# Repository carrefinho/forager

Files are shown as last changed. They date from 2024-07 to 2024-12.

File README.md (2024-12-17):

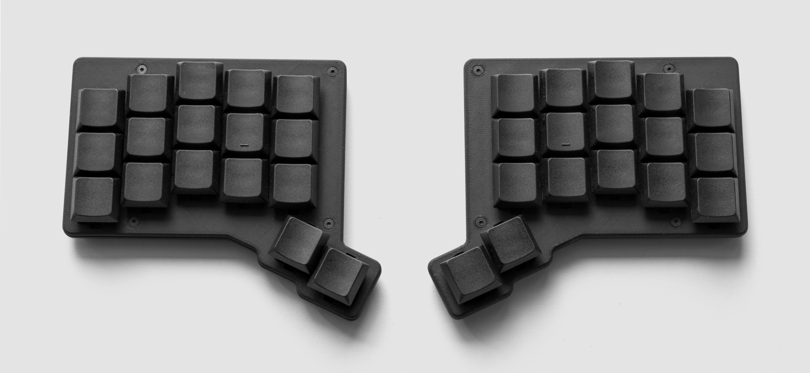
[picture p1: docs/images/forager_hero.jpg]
Forager keyboard in white


# Forager

Forager is a Voyager-inspired 34-key low-profile wireless split keyboard powered by ZMK.

> why does the large Voyager not simply eat the small Forager?

## Design

- Condensed [ZSA Voyager](https://www.zsa.io/voyager) layout without outer pinkie column and number row
- Hot-swap Kailh Choc V1 switches in Choc (18x17mm) spacing with Voyager-esque switch puller grooves

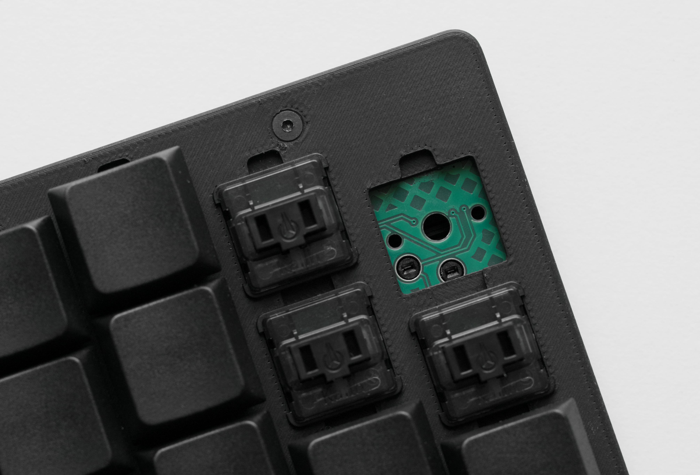
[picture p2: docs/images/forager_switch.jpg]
Switch-plate cutouts


- Wireless only with Seeed XIAO nRF52840 running ZMK firmware
- Magnetic tenting legs inspired by Voyager and [Unicorne](https://www.boardsource.xyz/products/unicorne)

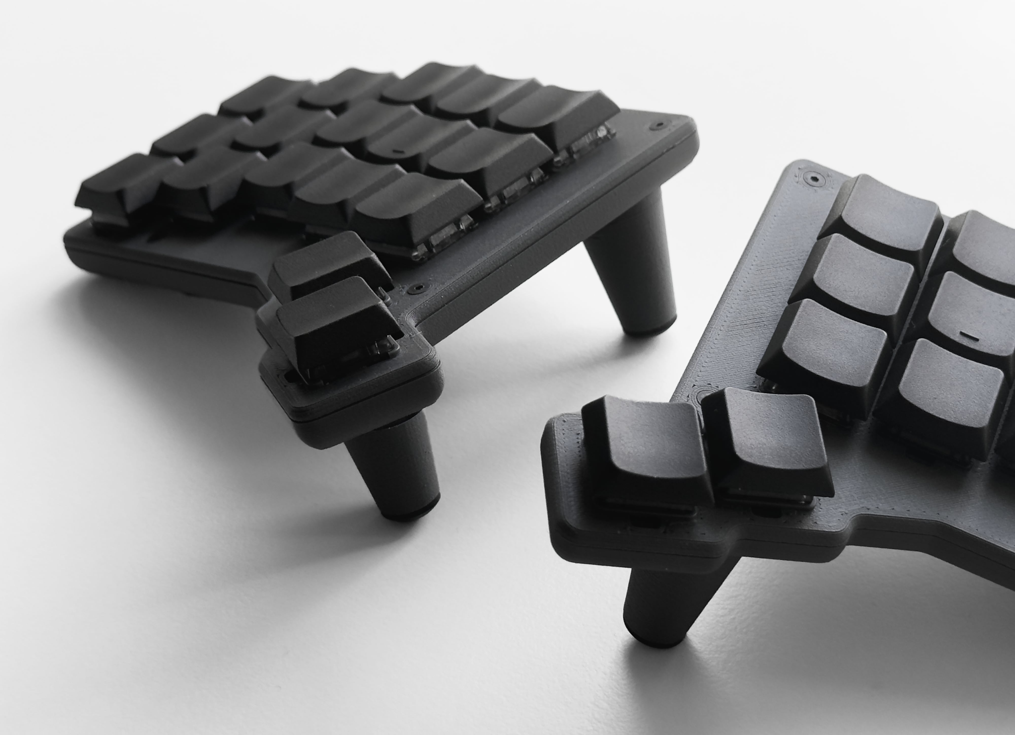
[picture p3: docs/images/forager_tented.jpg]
Forager keyboard with magnetic tenting legs attached


- Compact silhouette without the usual blank space occupied by controller
- Fully enclosed with 3D-printed two-piece case
- Minimal BOM by utilizing XIAO nRF52840's onboard RGB LED and reset button

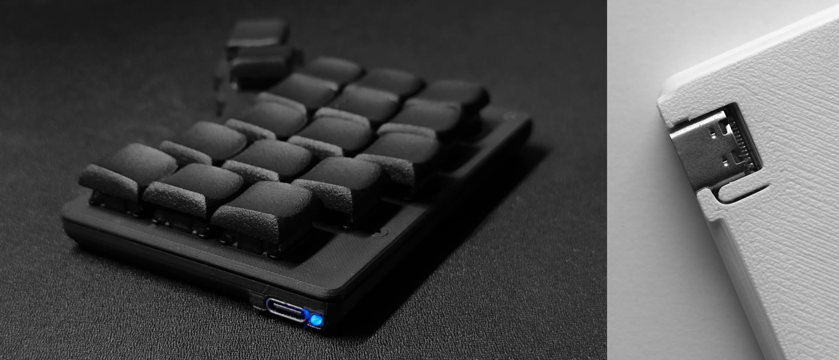
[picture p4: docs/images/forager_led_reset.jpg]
Forager keyboard with LED indicator lit up in blue alongside reset button on the bottom


## Build Guide and Parts List

[Find the build guide here.](/docs/build-guide.md)

## Firmware

[Find the ZMK module here.](https://github.com/carrefinho/forager-zmk-module)

## Credits

- [ZSA Voyager](https://www.zsa.io/voyager): overall layout & aesthetics
- [GEIGEIGEIST/TOTEM](https://github.com/GEIGEIGEIST/TOTEM): XIAO PCB footprint and general placement
- [ebastler/marbastlib](https://github.com/ebastler/marbastlib): symbols and PCB footprints
- [caksoylar/zmk-rgbled-widget](https://github.com/caksoylar/zmk-rgbled-widget): RGB LED functionality

## Gallery

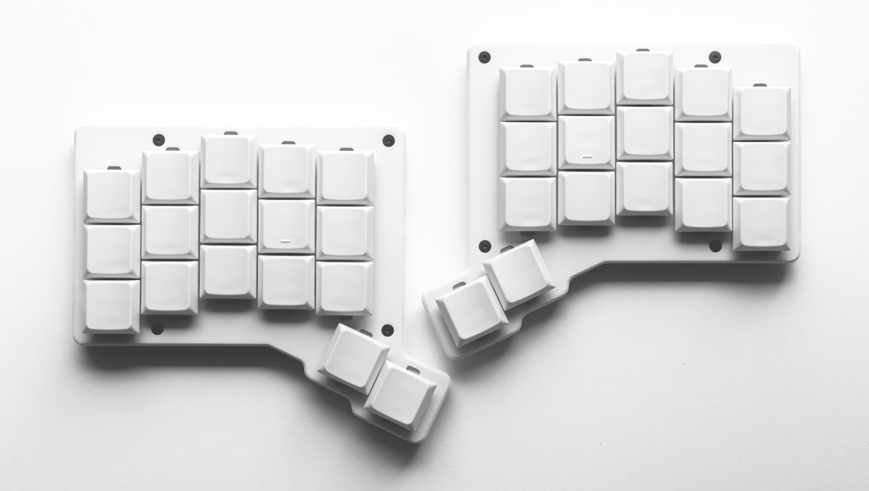
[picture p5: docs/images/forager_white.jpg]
Forager keyboard in white

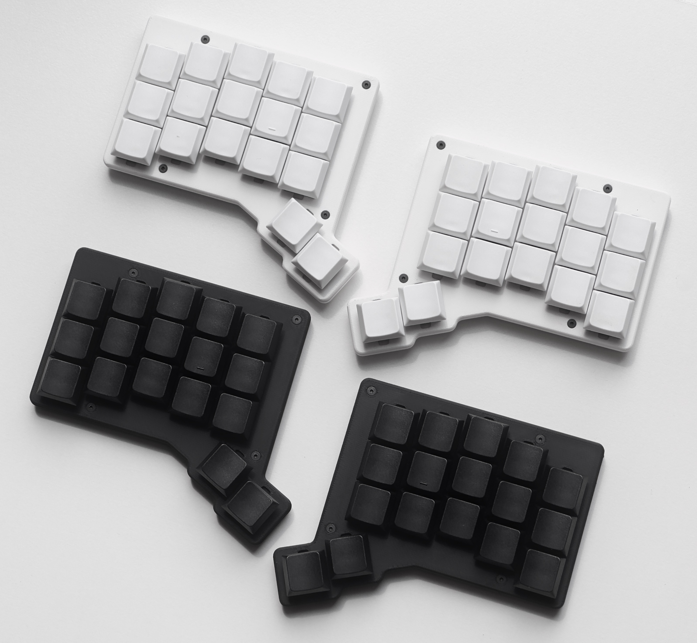
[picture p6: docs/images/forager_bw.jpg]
Forager keyboard in black and white

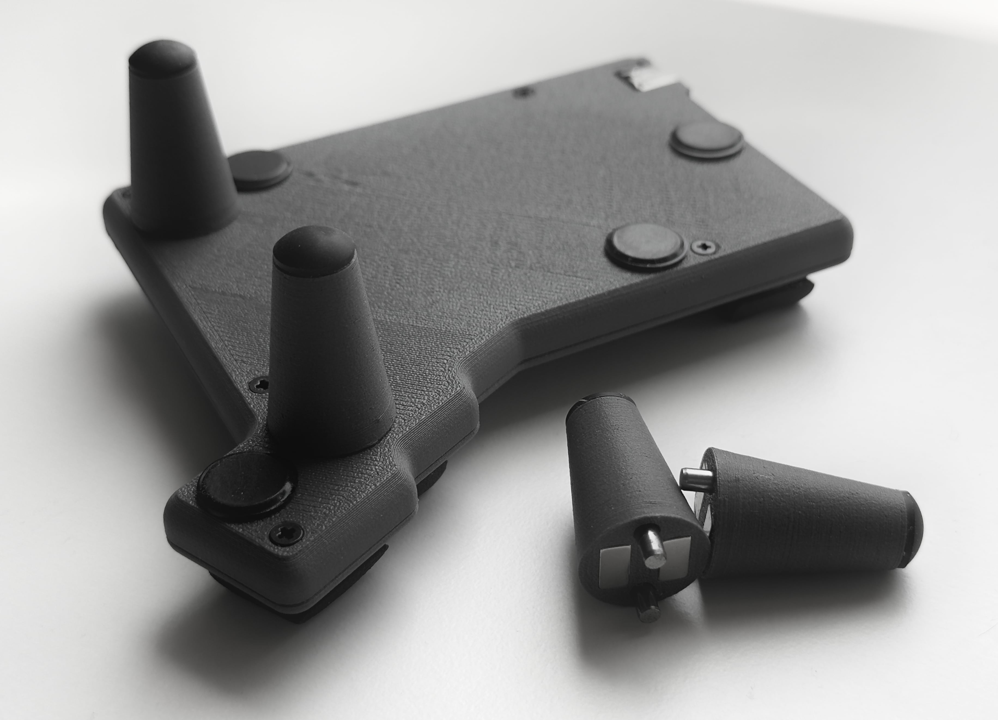
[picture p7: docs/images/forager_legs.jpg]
Forager keyboard with detached tenting leg

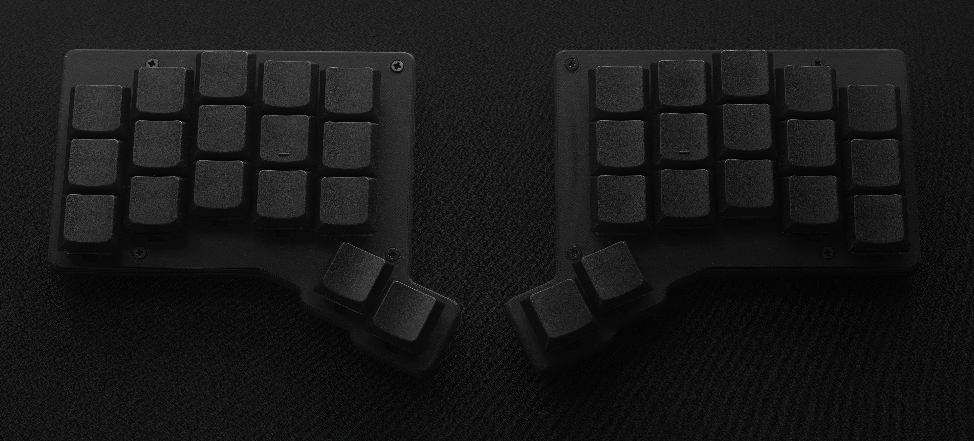
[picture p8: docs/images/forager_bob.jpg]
Forager keyboard in black


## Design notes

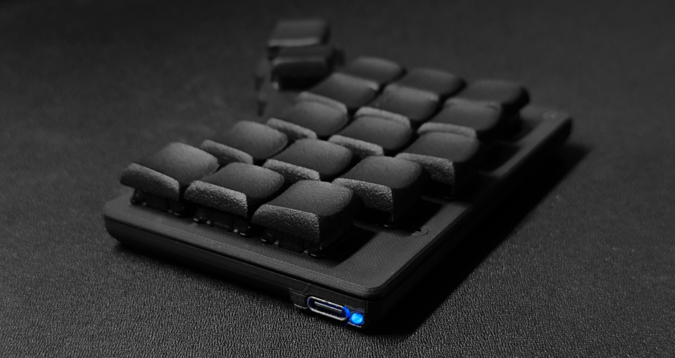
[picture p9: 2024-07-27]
docs/images/forager_led.jpg

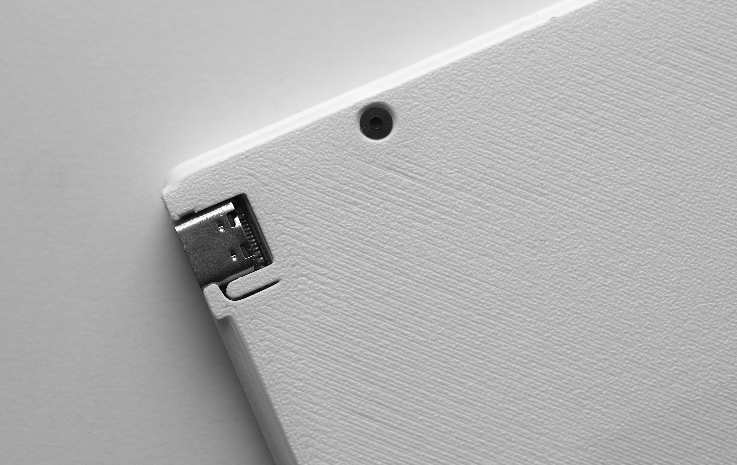
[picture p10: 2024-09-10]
docs/images/forager_reset.jpg

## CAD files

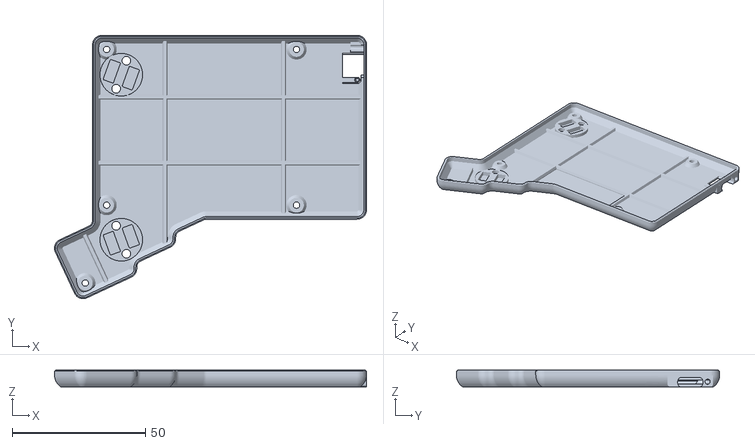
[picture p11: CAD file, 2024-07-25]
case/RBase.stl
117.2 x 98.9 x 6.20

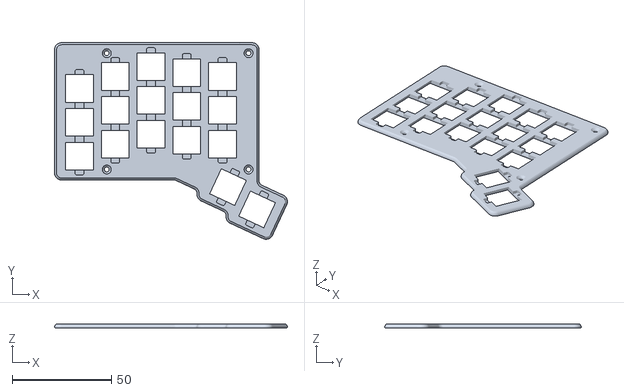
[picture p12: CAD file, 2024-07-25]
case/LTop.stl
117.2 x 98.9 x 2.20

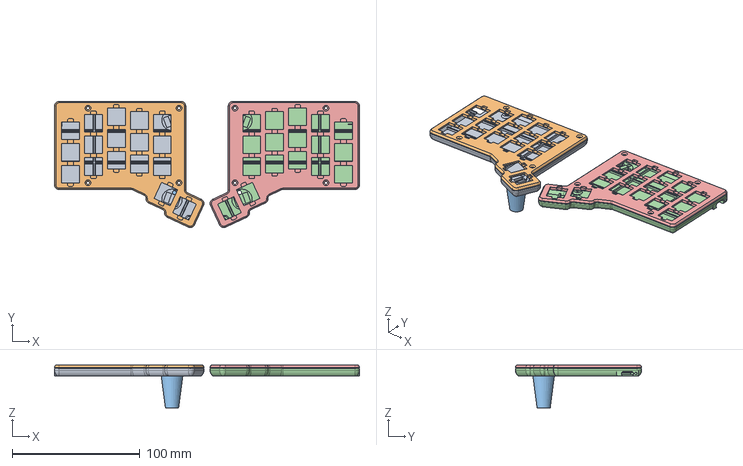
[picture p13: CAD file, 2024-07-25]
case/Forager Case.step
239.1 x 98.9 x 33.4 mm

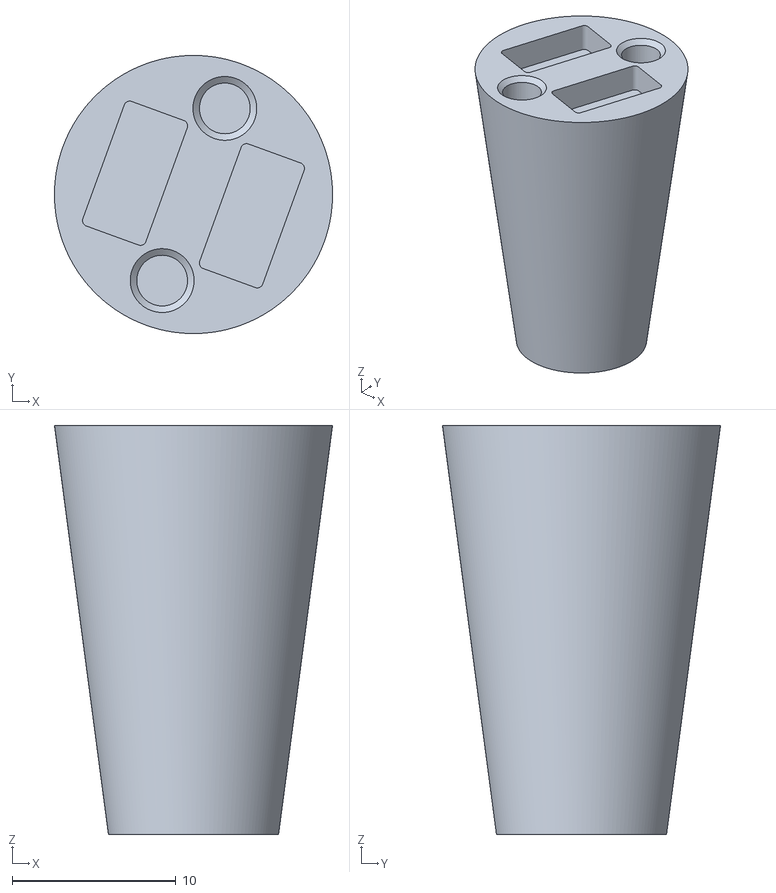
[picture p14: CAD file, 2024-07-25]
case/legs.stl
17.0 x 17.0 x 25.0

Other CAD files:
case/LBase.stl
case/RTop.stl

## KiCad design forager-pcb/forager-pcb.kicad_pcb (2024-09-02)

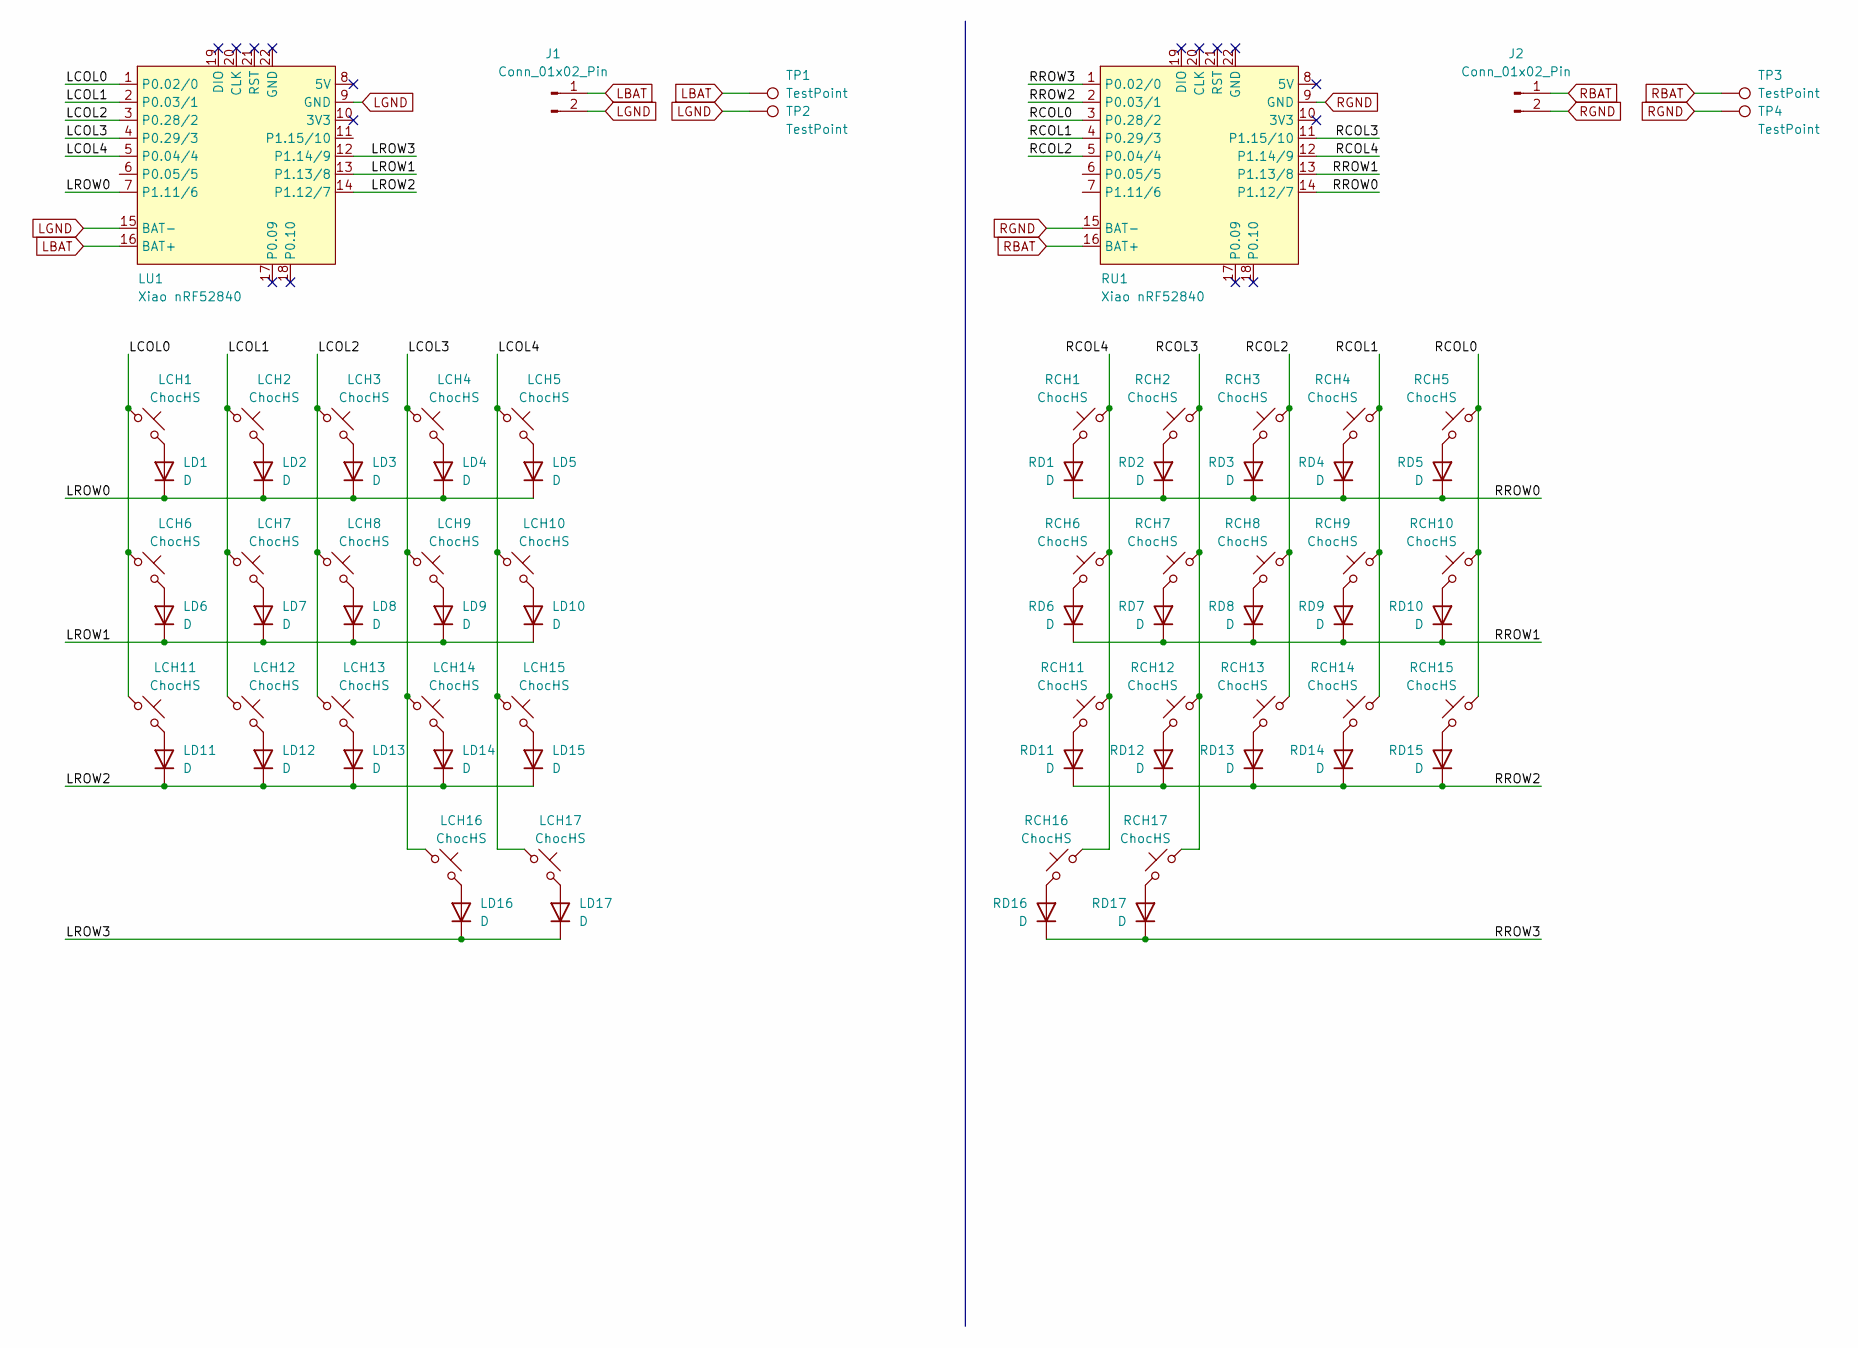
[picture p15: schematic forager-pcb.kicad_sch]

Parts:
J1, J2: Conn_01x02_Pin; JST_ACH_BM02B-ACHSS-GAN-ETF_1x02-1MP_P1.20mm_Vertical
LCH1, LCH2, LCH3, LCH4, LCH5, LCH6, LCH7, LCH8, LCH9, LCH10, LCH11, LCH12, LCH13, LCH14, LCH15, LCH16, LCH17: ChocHS; SW_choc_v1_HS_MBK
LD1, LD2, LD3, LD4, LD5, LD6, LD7, LD8, LD9, LD10, LD11, LD12, LD13, LD14, LD15, LD16, LD17: D; D_SOD-123
LU1: Xiao nRF52840; xiao-ble-smd-cutout
RCH1, RCH2, RCH3, RCH4, RCH5, RCH6, RCH7, RCH8, RCH9, RCH10, RCH11, RCH12, RCH13, RCH14, RCH15, RCH16, RCH17: ChocHS; SW_choc_v1_HS_MBK
RD1, RD2, RD3, RD4, RD5, RD6, RD7, RD8, RD9, RD10, RD11, RD12, RD13, RD14, RD15, RD16, RD17: D; D_SOD-123
RU1: Xiao nRF52840; xiao-ble-smd-cutout
TP1, TP2, TP3, TP4: TestPoint; TestPoint_Pad_D2.0mm

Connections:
/LCOL0: LCH1.1, LCH6.1, LCH11.1, LU1.1 (P0.02/0)
/LCOL1: LCH2.1, LCH7.1, LCH12.1, LU1.2 (P0.03/1)
/LCOL2: LCH3.1, LCH8.1, LCH13.1, LU1.3 (P0.28/2)
/LCOL3: LCH4.1, LCH9.1, LCH14.1, LCH16.1, LU1.4 (P0.29/3)
/LCOL4: LCH5.1, LCH10.1, LCH15.1, LCH17.1, LU1.5 (P0.04/4)
/LROW0: LD1.1 (K), LD2.1 (K), LD3.1 (K), LD4.1 (K), LD5.1 (K), LU1.7 (P1.11/6)
/LROW1: LD6.1 (K), LD7.1 (K), LD8.1 (K), LD9.1 (K), LD10.1 (K), LU1.13 (P1.13/8)
/LROW2: LD11.1 (K), LD12.1 (K), LD13.1 (K), LD14.1 (K), LD15.1 (K), LU1.14 (P1.12/7)
/LROW3: LD16.1 (K), LD17.1 (K), LU1.12 (P1.14/9)
/RCOL0: RCH5.1, RCH10.1, RCH15.1, RU1.3 (P0.28/2)
/RCOL1: RCH4.1, RCH9.1, RCH14.1, RU1.4 (P0.29/3)
/RCOL2: RCH3.1, RCH8.1, RCH13.1, RU1.5 (P0.04/4)
/RCOL3: RCH2.1, RCH7.1, RCH12.1, RCH17.1, RU1.11 (P1.15/10)
/RCOL4: RCH1.1, RCH6.1, RCH11.1, RCH16.1, RU1.12 (P1.14/9)
/RROW0: RD1.1 (K), RD2.1 (K), RD3.1 (K), RD4.1 (K), RD5.1 (K), RU1.14 (P1.12/7)
/RROW1: RD6.1 (K), RD7.1 (K), RD8.1 (K), RD9.1 (K), RD10.1 (K), RU1.13 (P1.13/8)
/RROW2: RD11.1 (K), RD12.1 (K), RD13.1 (K), RD14.1 (K), RD15.1 (K), RU1.2 (P0.03/1)
/RROW3: RD16.1 (K), RD17.1 (K), RU1.1 (P0.02/0)
LBAT: J1.1, LU1.16 (BAT+), TP1.1
LGND: J1.2, LU1.9 (GND), LU1.15 (BAT-), TP2.1
unnamed: LCH1.2, LD1.2 (A)
unnamed: LCH2.2, LD2.2 (A)
unnamed: LCH3.2, LD3.2 (A)
unnamed: LCH4.2, LD4.2 (A)
unnamed: LCH5.2, LD5.2 (A)
unnamed: LCH6.2, LD6.2 (A)
unnamed: LCH7.2, LD7.2 (A)
unnamed: LCH8.2, LD8.2 (A)
unnamed: LCH9.2, LD9.2 (A)
unnamed: LCH10.2, LD10.2 (A)
unnamed: LCH11.2, LD11.2 (A)
unnamed: LCH12.2, LD12.2 (A)
unnamed: LCH13.2, LD13.2 (A)
unnamed: LCH14.2, LD14.2 (A)
unnamed: LCH15.2, LD15.2 (A)
unnamed: LCH16.2, LD16.2 (A)
unnamed: LCH17.2, LD17.2 (A)
unnamed: RCH1.2, RD1.2 (A)
unnamed: RCH2.2, RD2.2 (A)
unnamed: RCH3.2, RD3.2 (A)
unnamed: RCH4.2, RD4.2 (A)
unnamed: RCH5.2, RD5.2 (A)
unnamed: RCH6.2, RD6.2 (A)
unnamed: RCH7.2, RD7.2 (A)
unnamed: RCH8.2, RD8.2 (A)
unnamed: RCH9.2, RD9.2 (A)
unnamed: RCH10.2, RD10.2 (A)
unnamed: RCH11.2, RD11.2 (A)
unnamed: RCH12.2, RD12.2 (A)
unnamed: RCH13.2, RD13.2 (A)
unnamed: RCH14.2, RD14.2 (A)
unnamed: RCH15.2, RD15.2 (A)
unnamed: RCH16.2, RD16.2 (A)
unnamed: RCH17.2, RD17.2 (A)
RBAT: J2.1, RU1.16 (BAT+), TP3.1
RGND: J2.2, RU1.9 (GND), RU1.15 (BAT-), TP4.1

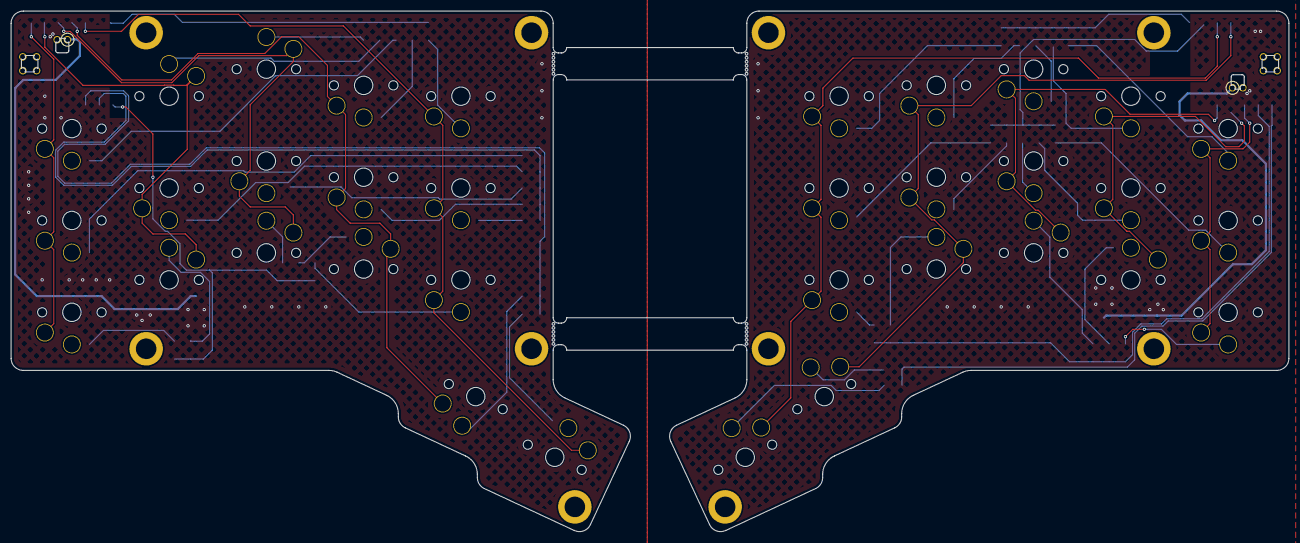
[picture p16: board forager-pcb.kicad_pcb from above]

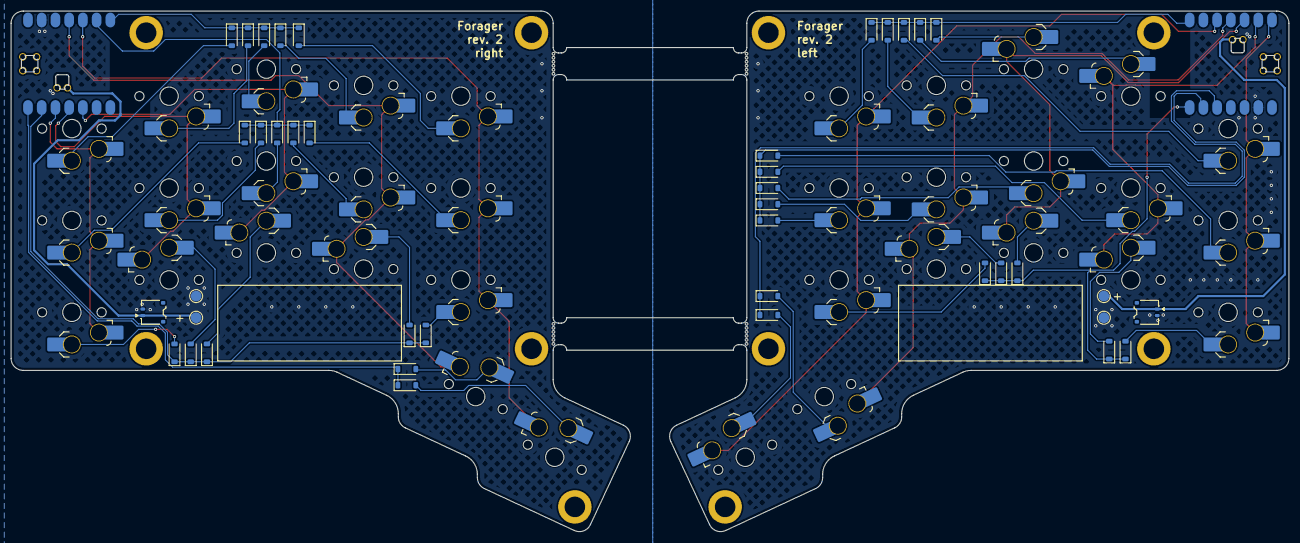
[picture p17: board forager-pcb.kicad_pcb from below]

Board: 2 copper layers, 236.5 x 96.3 mm, 76 parts (76 on the bottom side), 56 nets.

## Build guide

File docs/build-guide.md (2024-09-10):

# Forager Build Guide

## List of Components

| Part Name | Part Number | Count | Notes |
| --- | --- | ----- | ----- |
| Forager PCB | - | 1 | [Files here.](../forager-pcb/) |
| Seeed XIAO nRF52840 | - | 2 | Including Sense version; not compatible with other variants of the XIAO including RP2040 and ESP32-C3 |
| Choc V1 hot swap sockets | CPG135001S30 | 34 | |
| Diodes | 1N4148W | 34 | SOD-123 | - |
| Battery Connector | JST BM02B-ACHSS-GAN / MOLEX 781710002 | 2 (OPTIONAL) | Only required for batteries with JST ACH/Molex Pico-EZmate connectors. The two types should be compatible in both PCB footprint and physical connector.
| Battery | 301230 / 401230 | 2 | Widely available from many keyboard vendors. [Little Keyboards sell ones with JST ACH connectors](https://www.littlekeyboards.com/collections/new-products/products/battery-w-jst-connector) for use with the connector above.
| SMD M2 Nuts | SMTSO2020MTJ | 10 | https://www.lcsc.com/product-detail/SMD-round-nut_Sinhoo-SMTSO2020MTJ_C2916384.html |

### Case

| Part Name | Part Number | Count | Notes |
| --- | --- | ----- | ----- |
| 3D-printed Case | - | 4 | [Files here.](../case/) Designed for FDM. Some walls may be too thin for certain technologies.
| Countersunk M2 Screws | - | 18 | Total length 4-5mm. https://www.mcmaster.com/91294A002/
| Rubber Bumpers | - | 8+ | Anything not too thick will do. https://www.mcmaster.com/95495K18/
| LED Light Guide | - | 2 | 1.75mm  transparent filament segment, 6mm length |

### Tenting Legs

| Part Name | Part Number | Count | Notes |
| --- | --- | ----- | ----- |
| Locating Pins | McMaster-Carr 97049A206 | 8 | https://www.mcmaster.com/97049A206/ |
| 8mm x 4mm x 2mm Rectangular Magnets | Apex Magnets M8x4x2MMBL | 8 | https://www.apexmagnets.com/magnets/8mm-x-4mm-x-2mm-block-neodymium-magnet |
| Rubber Bumpers | - | 4 | 10mm diameter, preferably hemispherical.

## PCB

Forager is designed exclusively for surface mounting the controller board, therefore it's not compatible with sockets.

This guide assumes that you're using a soldering iron; you can use a hot plate or hot air gun with solder paste. Low temp paste is preferred if you'd like to remove the XIAO later since it's less likely to mess up components on the XIAO itself.

Images shown are of an older revision of the board, without battery pads for direct wiring; everything else still apply.

- Break off the two halves from each other.
   - There will be some leftover bits from the mouse bites; leave them alone as they're not exposed and won't interfere with the case.

- Solder everything.

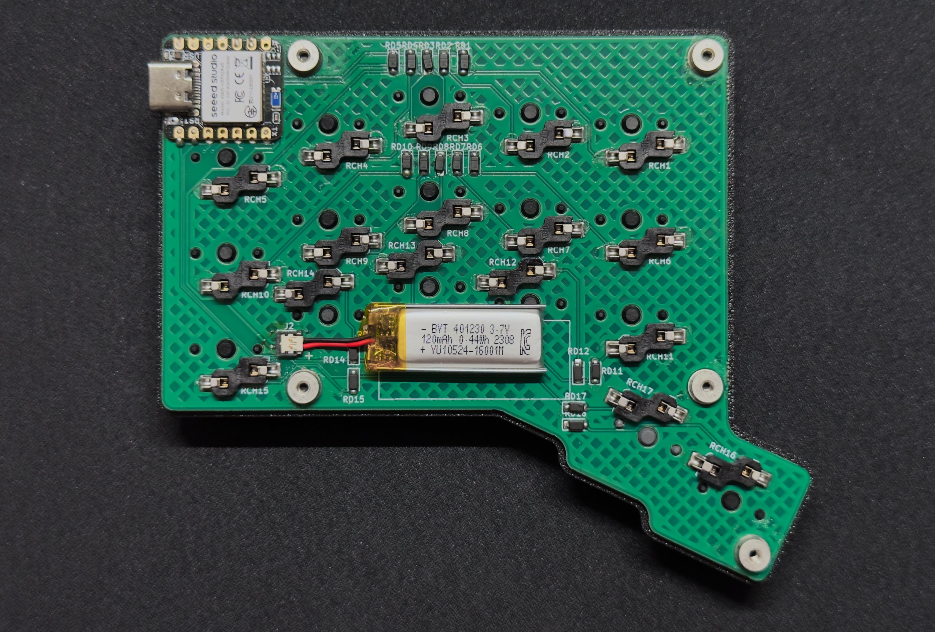
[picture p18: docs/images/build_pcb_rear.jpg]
fully soldered PCB
   

   - Start with the back side of the PCB where all the silkscreen is.
   - XIAO nRF52840
      - Solder two pads on opposite corners first to anchor it in place. Make sure it is lined up with the pads both horizontally and vertically.
      - Solder all remaining pads.
      - Flip the board over and solder the pin marked with a circle; this is the battery+ pin. You may want to stick the iron in the cutout to make sure solder bonds with the pad properly. Flip the board back around.
   - Hot-swap sockets and diodes
      - Tin one pad first to anchor the diode/socket in place.
      - Solder the other pad.
      - Make sure the line on the diode package matches the direction of the silkscreen.
   - SMD Nuts
      - Place them in their respective holes; make sure they're fully seated. They should be sticking out towards the back like all other components.
      - Apply solder around the perimeter; flux is recommended.
      - Remove the protective tape.
   - ***OPTIONAL*** - Battery Connector
      - It is recommended to solder these with a hot plate or hot air, since the two mounting pads are difficult to reach with an iron and if not soldered properly, the connector may lift off the board entirely when removing the battery.
      - Tin one of the mounting pads (the wider ones), place the connector, make sure the electrical pads are lined up and reheat that pad again from the opening side.
      - Solder the other mounting pad and the electrical pads.
   - Battery without connector
      - Trim the battery wires to an appropriate length that they reach the circular pads with the battery itself inside the rectangle.
      - Solder the red wire to the pad marked +, and the black wire to the other.

## Case

- Print the four case parts. Pay attention to the print-in-place reset lever button on the base; it might fuse together with the surrounding and get stuck depending on the amount of first layer squish. Adjust z-offset if needed.

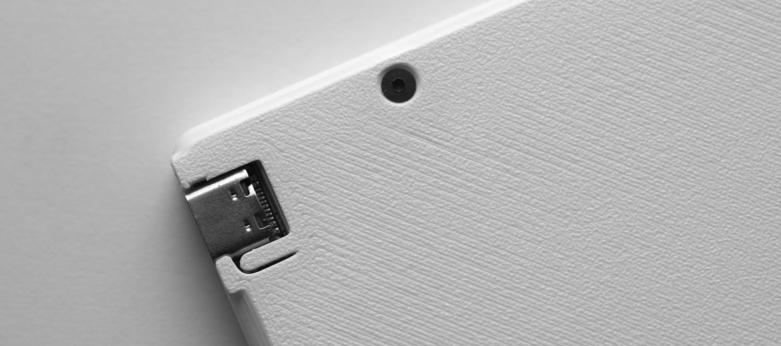
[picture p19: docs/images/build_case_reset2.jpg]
case with reset lever button


- Cut two 6mm segments of transparent 3D-printing filament (1.75mm diameter).
   - From the inside, insert one into the slot in the case.
   - It might require some convincing; use a small pointy tool like an allen key to push it through the hole and then adjust back until it's flush with the case.

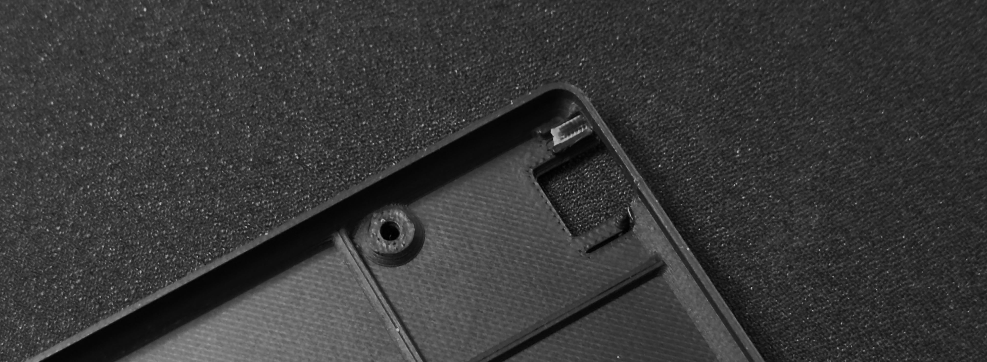
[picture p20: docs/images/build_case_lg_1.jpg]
case light guide 1
   
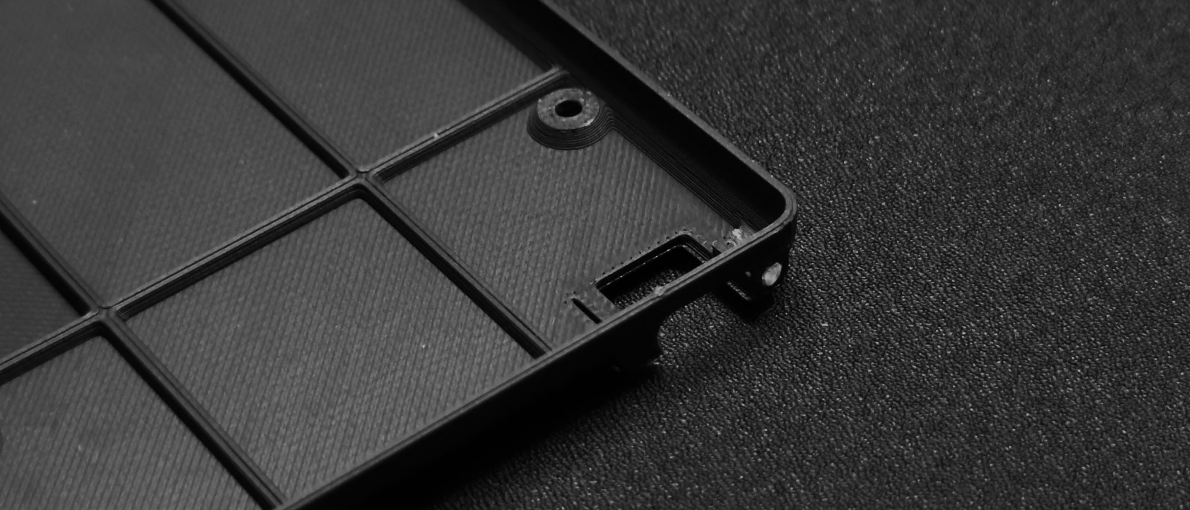
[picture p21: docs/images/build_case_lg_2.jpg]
case light guide 2
   
- Place the plate/top part on the front side of the PCB.
   - Install a couple of switches around the corners to align it with the PCB.
   - Then screw it in.
- Flip it around and install the base/bottom part.
   - Go first on the USB-C port side; make sure it's snug inside the cutout.
   - Once everything fits nicely together, screw it in.
   - You may want hold the top and bottom part together along the edges to make sure they're lined up while screwing in.

## Tenting Legs

- Insert two Pins and two Magnets into the tenting leg. It should be a very tight friction fit.
   - Apply the adhesive 10mm rubber bumper to the other end.
- Install two magnets into the cutouts inside the bottom case.
- Make sure all magnets are of the same orientation so that tenting legs all have the same polarity.

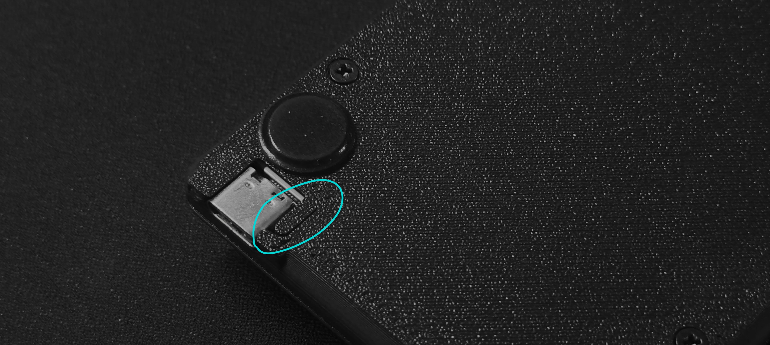
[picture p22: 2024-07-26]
docs/images/build_case_reset.jpg

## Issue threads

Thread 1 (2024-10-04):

Question: Do you have any plans for making a 4x6 version of this?

csntr, 2024-10-04:
As said in the title, I really love the look, and I would immediately build a 4x6 version of it. Did you have any plans of creating one?

carrefinho, 2024-10-15:
I have some ideas for a small revision; six column could be on the cards for that. Although with the controller position it has to be a separate PCB design and can't be a break-away column like other boards.

t0bybr, 2024-10-20:
What do you plan for the revision? I really want to build this as it's beautiful and smart. I also love the case details like the reset button. I'm wondering if I should wait.

AMoynahan89, 2024-10-30:
Beautiful build, this is the keyboard I was going to build from scratch so thanks for doing all the hard work. How is the battery life on it and would it be possible to fit a bigger battery in that case or is it pretty full?

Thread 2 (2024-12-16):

Question: How long is the battery life?

aymane-eljerari, 2024-12-16:
I'm excited to build this, and im wondering how long the battery lasts. What's the largest battery I could fit in the case?

carrefinho, 2024-12-16:
One to two weeks on the left side (central), two to three months on the right side (peripheral). It's designed around the commonly available 110mAh 301230 battery, and because of the compact footprint, there is only a couple millimeters of extra room.

lukeberry99, 2025-01-01:
Out of curiosity, would this work having a third microcontroller as a “dongle” that is permanently plugged in, giving both halves two to three months battery life?

carrefinho, 2025-01-01:
@lukeberry99
Yes, that is an option. There is [work-in-progress documentation in the ZMK docs](https://deploy-preview-2525--zmk.netlify.app/docs/development/hardware-integration/dongle).
Also check out [Prospector](https://github.com/carrefinho/prospector) for a fancy dongle.

lightningspirit, 2025-03-11:
@carrefinho Would a LiPo 301430 (32x14x4) which is 150 mAh fit in this case?

lightningspirit, 2025-05-13:
> Would a LiPo 301430 (32x14x4) which is 150 mAh fit in this case?

If anyone is wondering, I was able to use this battery in the case successfully.

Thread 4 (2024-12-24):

Question: What MCU back pads to solder?

ahan98, 2024-12-24:
Hi,

Is the BAT+ pad on the back of the XIAO BLE the only pad on that side to solder? Are there any other pads that need to be soldered on that side (e.g., RST, GND, etc.)?

Thanks!

carrefinho, 2024-12-24:
BAT+ is the only one.

Closed 2024-12-24.

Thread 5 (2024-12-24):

Feature: integrated trackpoint module

artsbentley, 2024-12-24:
Hi, first of all thank you for all the effort you clearly put into this board, it looks super clean.

I was wondering if there are any plans to implement trackpoint module integration in the future. I'm currently quite happy with my Totem as main keyboard, but the one thing missing is integrated mouse pointer, which would be amazing on a wireless board.

carrefinho, 2024-12-26:
Trackpoints are a bit tricky because there are many different types of modules out there with no clear go-to, they require custom keycaps, and have rather high power consumption.

A trackpad or small trackball are more likely options if Forager would integrate a pointing device in the future.

twop, 2025-03-01:
Im actually curious about integrated trackpad module (possibly the very small one)

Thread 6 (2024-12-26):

Bluetooth not working, only works over USB

ahan98, 2024-12-26:
The keyboard works with both halves plugged into my laptop over USB, but I'm unable to get connectivity over bluetooth.

Here are the exact steps I followed:

1. Fork the Forager ZMK module: https://github.com/carrefinho/forager-zmk-module
2. Push any changes to the fork and download the firmware from the workflow in the Actions tab.
3. Plug in the left half. Double tap the reset button on the controller. Flash `settings_reset-seeeduino_xiao_ble-zmk.uf2` onto the controller.
4. Double tap the reset button on the left controller again. Flash `forager_left rgbled_adapter-seeeduino_xiao_ble-zmk.uf2`. Disconnect the left half.
5. Repeat steps 3 and 4 for the right half.

After connecting the left half to the laptop over USB, then connecting the right half to the laptop over USB, I verified that every layer of the keymap is working properly. But I'm unable to get the keyboard working over bluetooth.

I also tried the following:

- Connect the left half to the laptop over USB, then connect the right half to the laptop over USB. Press the reset button on both controllers simultaneously to pair the halves to each other.
- Forget the Forager keyboard on my laptop's list of bluetooth devices. Press the key mapped to `&bt BT_CLR_ALL`.
- Press the key mapped to `&out OUT_BLE`.

The last thing I can think of is to test with different lithium ion batteries. I don't think it's a soldering issue since every key of every keymap layer works when plugged in over USB.

For the sake of reproducibility, would you mind sharing how to connect over bluetooth, similar to your build guide for the hardware? I would think it's something similar to steps 1-5, since that seems to be the standard procedure for flashing ZMK firmware (for example, the [instructions for flashing ZMK firmware for the TOTEM keyboard](https://github.com/GEIGEIGEIST/zmk-config-totem?tab=readme-ov-file#how-to-use) are pretty much the same).

Thanks!

carrefinho, 2024-12-26:
Halves only talk to each other via Bluetooth. So if both halves are working while connected to USB, that means they're paired and connected.

Does the LED near the USB-C port light up when you click reset while on battery? If not, it's simply not getting power from the battery.

ahan98, 2024-12-26:
I see. Yeah, when either half is not connected to the PC over USB, the light near the USB-C port of the controller doesn't light up after pressing the reset button. I'll try swapping batteries and see if that resolves the issue. Thanks for the fast reply.

ahan98, 2024-12-26:
Ended up fixing it by reworking a cold joint on the BAT+ pad. Thanks again for the help!

Closed 2024-12-26.

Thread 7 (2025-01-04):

Curious about the Battery Connection

aymane-eljerari, 2025-01-04:
I see that only the BATTERY+ has to be soldered on the back side of the microcontroller. I was wondering why there is no connection to BATTERY-. Is it to avoid short circuiting + and -? I haven't looked at the pcb routing but I assume the XIAO BLE's GND pin on the front side is being used. In that case why not connect battery + to the 3.3V pin on the front side of the microcontroller?

carrefinho, 2025-02-11:
Yes, BAT- and GND are the same thing; ideally the cutout could just not expose BAT- to eliminate the possibility of shorting.
BAT+ is connected to battery charger and then 3.3V is regulated from battery voltage by a LDO. Connecting battery (3.7-4.2V ish) to 3.3V will blow up the nRF52840.

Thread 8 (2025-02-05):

Pinky column stagger question

twop, 2025-02-05:
I have Voyager, and I love it but I seem to experience similar issues:
1. Number row is useless for me
2. The extra pinky column makes tenting awkward, specifically I have to use wrist support to get the needed palm height
3. Key spacing is a bit much, my hands are not that large
4. Being wired is a pain, I travel frequently

Thus, Im super excited about the project!! It looks amazing!

However, I have one more issue:
5. Pinky stagger is not aggressive enough for me.

Hence, Im curious how choc spacing affected the overall feel? And related, it seems that pinky column stagger is about 1mm or so larger than on the voyager, Is that so?

Im super tempted to just ordering parts, but wanted to double check first

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

carrefinho, 2025-02-11:
Sadly I can't help with the direct comparison since I don't actually own a Voyager; I just found the idea of a 34-key wireless Voyager like quite interesting as a project. Although I've seen a couple of builds from Voyager owners and it seems like they all like Forager and some prefer it to their Voyager.

You're correct in your observation that pinky stagger is slightly increased vs Voyager; it's not a one-to-one recreation and I eyeballed some things when designing. I think the combination a reachy thumb cluster and mild pinky stagger has merit, and in practice I find Forager quite comfortable especially with Chicago Steno keycaps.

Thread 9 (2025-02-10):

Feature - Support Choc v2 (as well as v1) switches

preardon, 2025-02-10:
I was wondering what it would take to support Kailh Choc v2 switches, from my understanding its a small change to the footprint (larger centre hole).

I Would you be happy for this change to be made, I'm happy to contribute and raise a Pull Request if you were willing to accept the changes.  This would be my First Mechanical Keyboard build (although I've wanted to build one for quite a while) so I would appreciate an eye over any PR I do.

carrefinho, 2025-02-11:
There are some issues with Choc v2 support:

- The standard Choc v2 switch has an additional pin meant for mechanical support, but its location opposite to the existing pins means accommodating it in the PCB footprint would conflict with the MCU and battery
    - Newer POM Choc v2 switches don't have that pin but older ones still do
- There is no 18x17mm Choc spaced keycap with MX-style stem that you could buy off the shelf so the only option is 3D-printing basically

With these considerations I feel like the list of caveats with Choc v2 support would just be too long.

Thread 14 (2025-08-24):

[Help/Feature] Battery drains too quickly + suggestion for power switch

MSmaili, 2025-08-24:
@carrefinho  First of all, thank you so much for the keyboard, it’s fantastic. The build quality is excellent, and overall, it feels top-tier. I really appreciate the work that went into it.

This isn’t my first keyboard, and I’ve tried several others before. I built this one a couple of weeks ago, but I’ve been having issues with the battery life. Even when using it with the USB dongle, the battery only lasts about a week. That surprised me, since my other keyboards with dongles usually last at least a month.

I followed your build guides closely, with the PCB ordered from JLCPCB. I also use this keyboard when I travel. In my configuration, I’ve enabled both soft_off and deep sleep.

Here’s my dongle config:
https://github.com/MSmaili/zmk-config/blob/main/boards/shields/forager_dongle/forager_dongle.conf

And here’s the full keyboard config:
https://github.com/MSmaili/zmk-config/blob/main/config/default.conf

I suspect that the keyboard might not be fully powering down. When I enable soft_off, the keyboard stops responding to key presses until I switch it back on, but even then, why does the battery still drains much faster than expected? To rule out the battery itself, I’ve already tested with different ones, and the result is the same.

**Do you have any suggestions for how I can debug this? What should I check or test next?**

Again, I really love this keyboard; both the design and the idea of using screws on the PCB are brilliant. If I could suggest a couple of improvements for future revisions, if it is possible:

- Adding a power switch

- Replacing the JST connector with a through-hole JST 2.0 option, since it’s easier to solder and works with most batteries
   -  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

Thanks again for the great work on this project, and I’m looking forward to your advice.

BenRoe, 2025-08-24:
About the JST, it might be to heigh. There is little space at the bottom.

peterjc, 2025-10-02:
I see your switch placement on https://github.com/MSmaili/forager/tree/power-switch/case/case_with_power_switch (looking at the case files), on the side near Qwerty `A` or semicolon. I could load the PCB, but what part are you using?

And I agree the though hole JST 2.0 would be nice for the battery connection - very easy to buy batteries with that. Do we have 6mm of height clearance though?

MSmaili, 2025-10-03:
The power-switch is MSK12C02.

I agree i doubt we have that much space, judging by the battery, the battery fits closely. So no more room for something taller.

MSmaili, 2025-10-04:
> MSK12C02

MSmaili, 2025-10-04:
I accidentally closed this issue, and I do not have permission to re-open, but the power-switch forager can be found [here](https://github.com/MSmaili/forager/tree/power-switch). I can make a pull request, but I IDK if I should do it because #16 and #17  are newer and better proposals and have a different PCB. (they do not include the power switch though)

Closed 2025-10-04.

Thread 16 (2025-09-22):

Direct wiring with Seeed XIAO nRF52840 Plus

peterjc, 2025-09-22:
The Seeed XIAO nRF52840 Plus adds additional GPIO pins between the original ones, giving 20 in total, up from 11. This is more than enough to directly wire each of the 17 switches without any diodes, potentially much quicker & easier to solder?

It would mean a new PCB design and new firmware.

Is this a sensible idea, or am I overlooking something?

peterjc, 2025-09-26:
I note you use the Seeed XIAO nRF52840 Plus in the https://github.com/carrefinho/visorbearer - I copied the footprint in KiCad and had an explore.

I think a direct wired "Voyager Plus" PCB is doable (with new firmware to match of course), and you could probably have a battery cutout in the PCB allowing for a slightly thicker higher capacity battery too.

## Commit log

2024-07-25 add pcb files and license
    [BOM-Forager34.csv, forager-pcb.kicad_pcb, forager-pcb.kicad_sch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]
2024-07-25 clean up pcb files
    [BOM-Forager34.csv, wayfarer34.step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]
2024-07-25 add gerber file update readme add case files update pcb files
    [Forager Case.step, LBase.stl, LTop.stl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]
2024-07-26 add tenting legs section
2024-07-27 kicad: add antenna keepout zone
    [forager-pcb.kicad_pcb]
2024-07-28 update gerber with antenna keepout
2024-09-02 docs: update build guide and new photos
    [forager-pcb.kicad_pcb]
2024-09-10 docs: better photos of reset button
